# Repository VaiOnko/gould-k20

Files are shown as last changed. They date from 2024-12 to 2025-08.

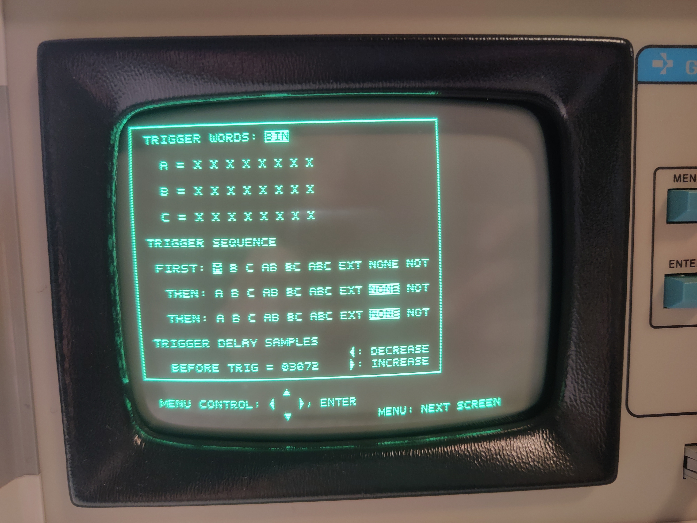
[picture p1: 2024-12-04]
pictures/menus/menu8.jpg

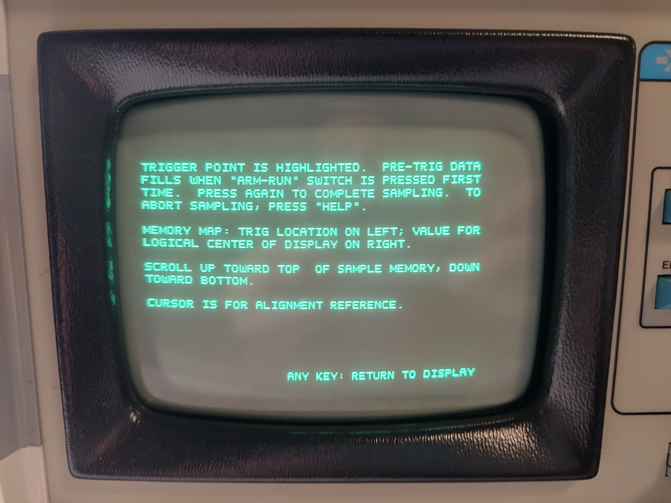
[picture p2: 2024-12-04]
pictures/menus/menu1.jpg

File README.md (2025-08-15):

# gould-k20

This probe is tested and works well according to my test without knowing how the proper thing operates,

This is my project to create a reproduction state mode probe for the Gould K20 logic analyzer and document the unit.

I did not get any probes with the unit, so I had to create my own one from scratch. 
The probe contains logic to route the three clock inputs to any combination of the three clocks on the analyzer. They can also be inverted and ORred together. All this is configured from the unit itself in the menu pictured in menu4.jpg, and sent to a pair of shift registers in the probe. 

The probe connects to the main unit with a 34-pin ribbon cable. I use a PC floppy cable from which I removed the twist. 

The probe should work just like the original state mode probe, but I cannot be sure as I don't know anything about the original one.
The machine also came with an 8-channel timing mode probe. From what I understand, it had a configurable clock generator inside and thus would be quite difficult to recreate. 

The directory "logicanalyzer" contains the KiCad project for the probe. 
The directory "pictures" contains detailed pictures of the unit.
The directory "ROMs" contains dumps from all the ROMs in the system.

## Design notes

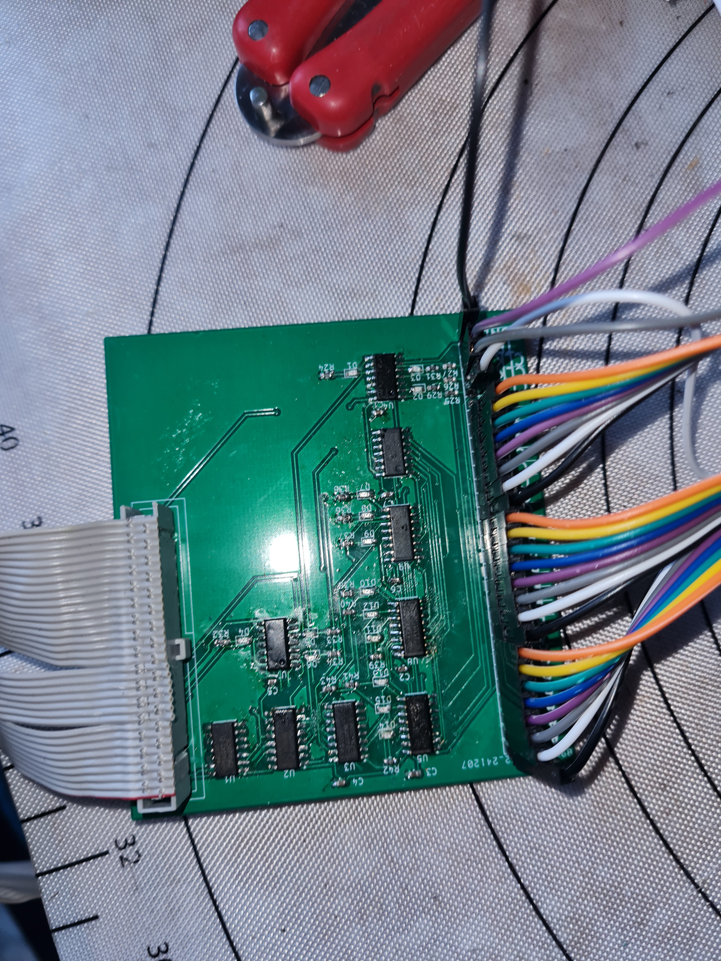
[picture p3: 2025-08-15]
pictures/the-probe.jpg

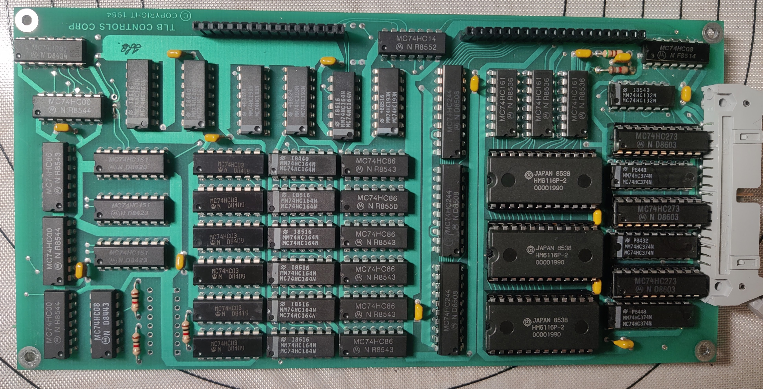
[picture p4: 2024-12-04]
pictures/interior/acquisition-board-1.jpg

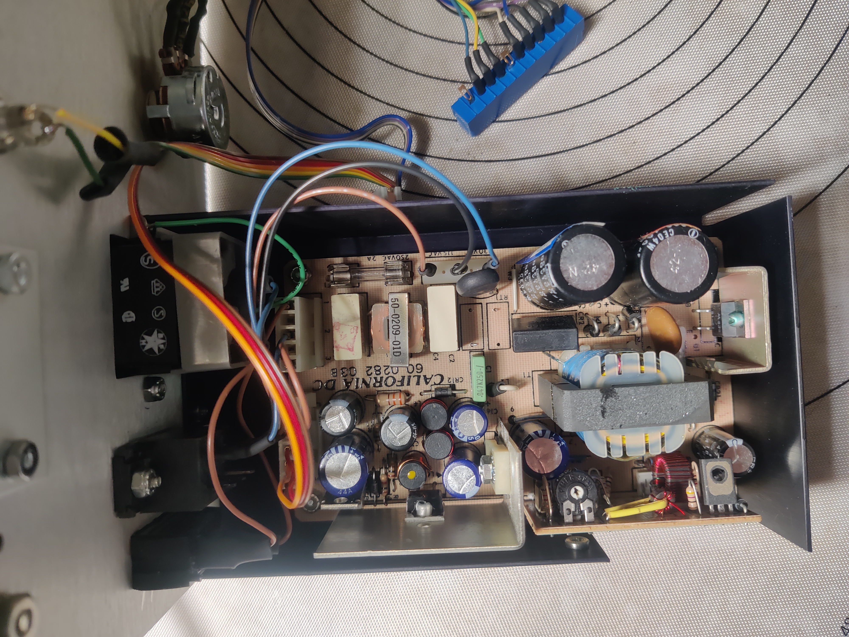
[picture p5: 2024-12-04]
pictures/interior/power-supply.jpg

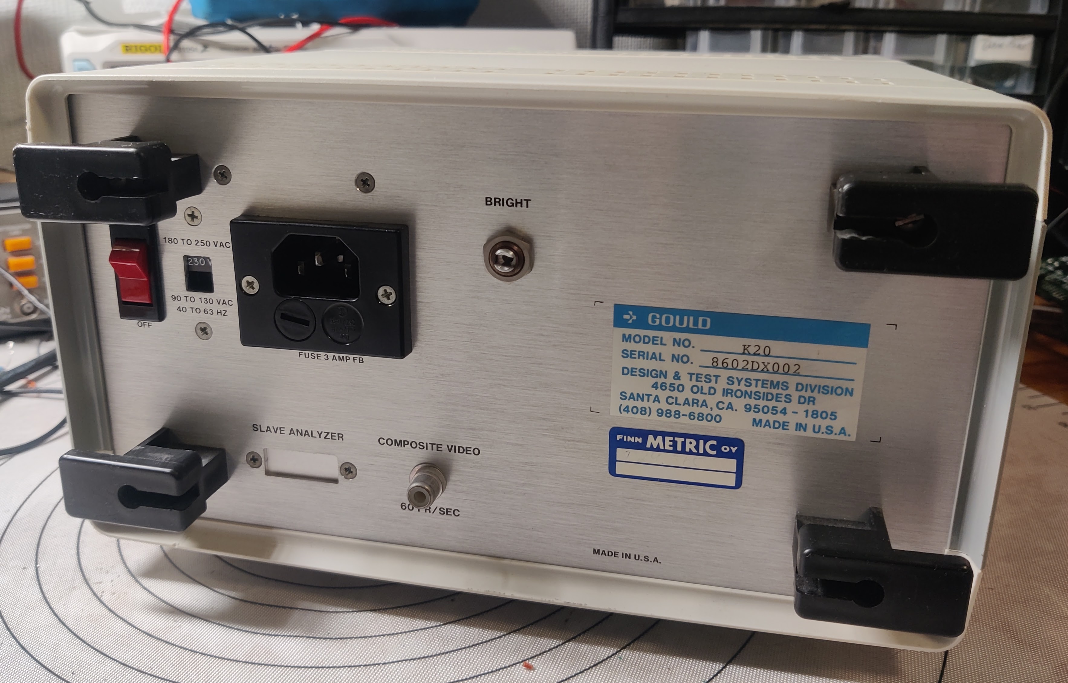
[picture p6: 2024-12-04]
pictures/exterior/rear.jpg

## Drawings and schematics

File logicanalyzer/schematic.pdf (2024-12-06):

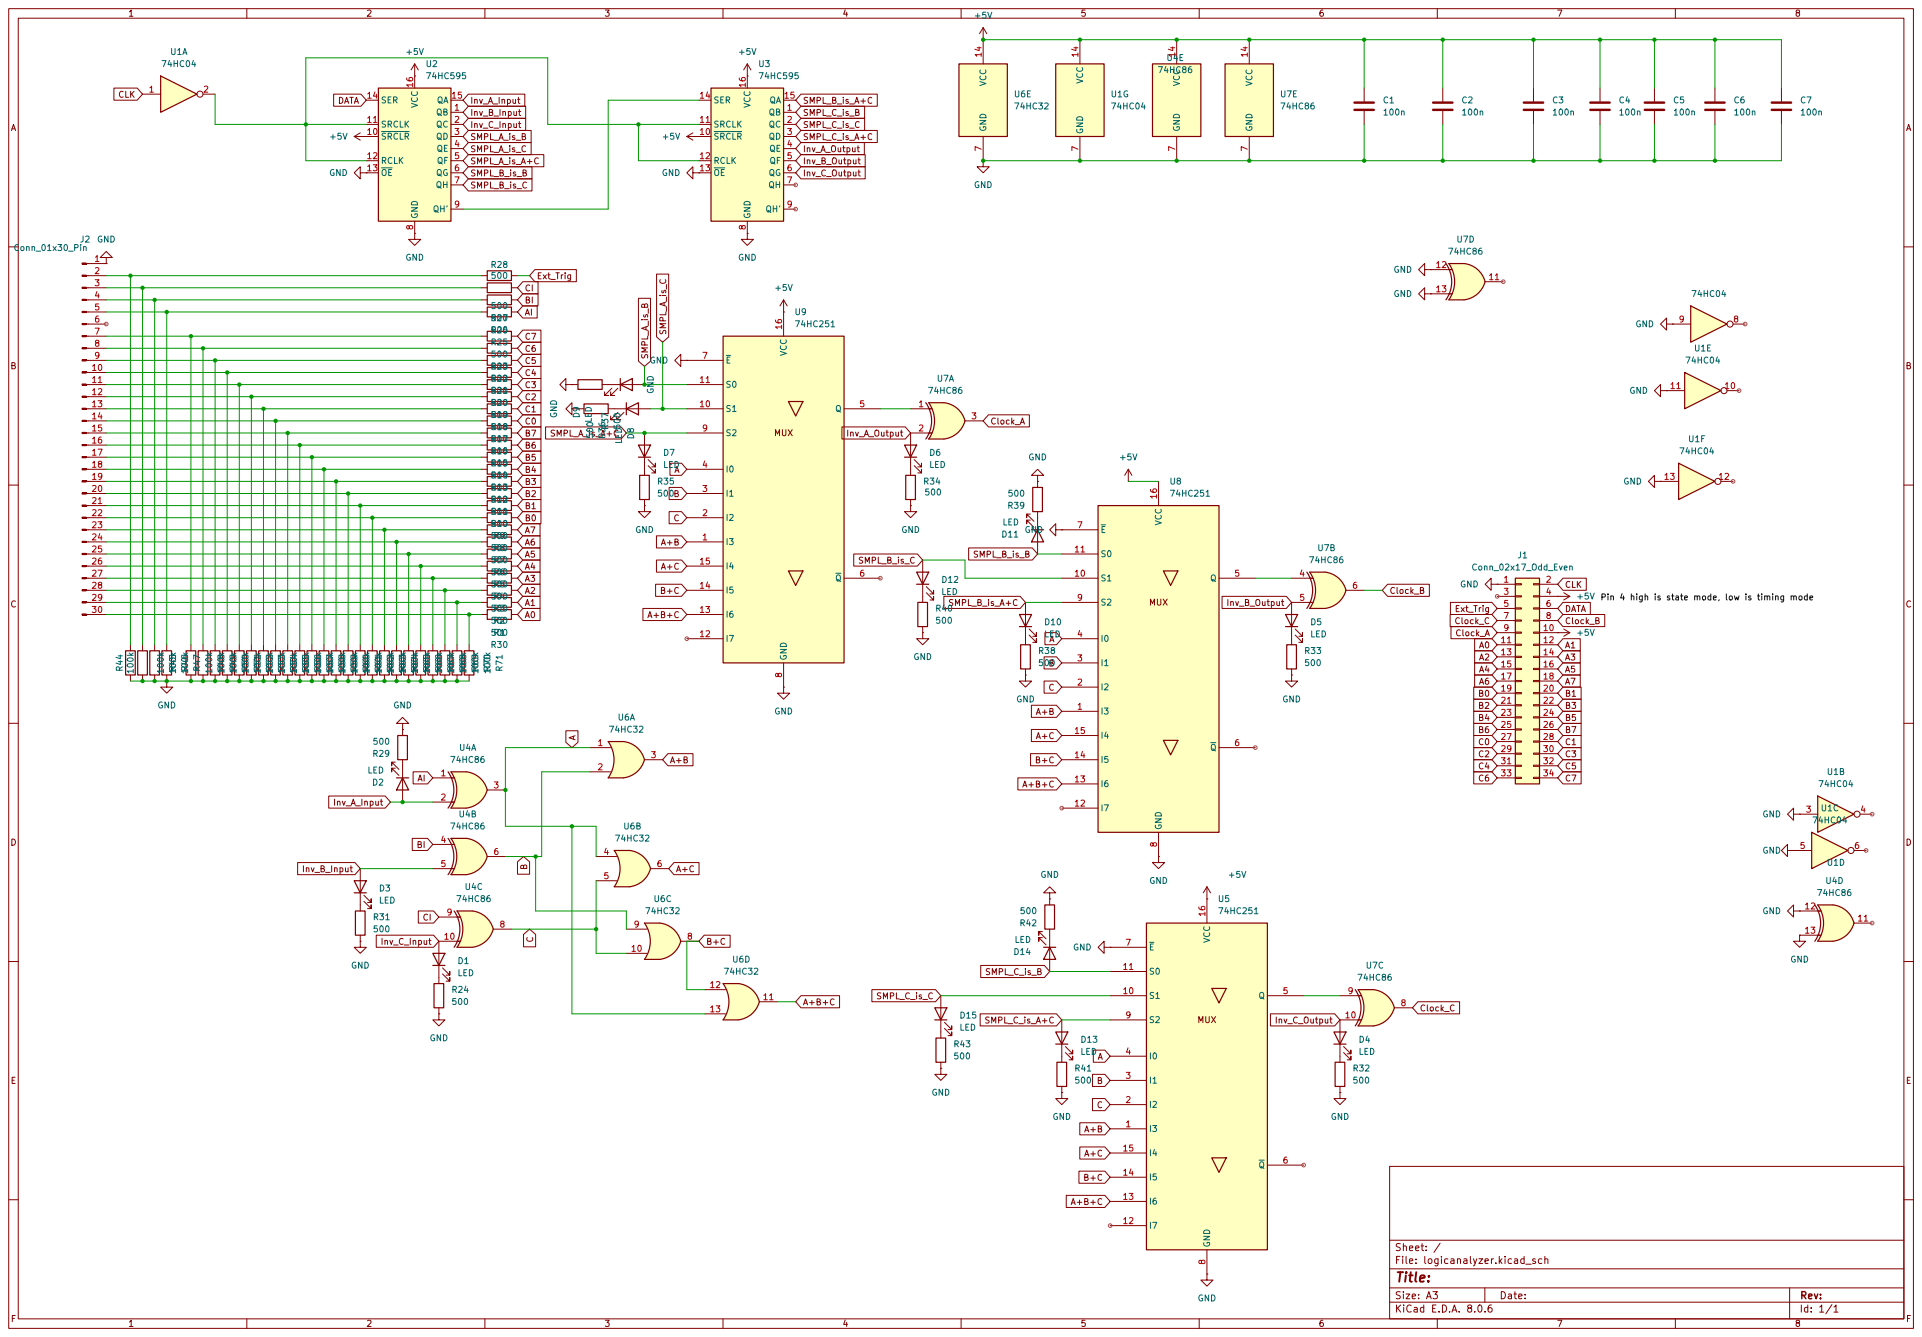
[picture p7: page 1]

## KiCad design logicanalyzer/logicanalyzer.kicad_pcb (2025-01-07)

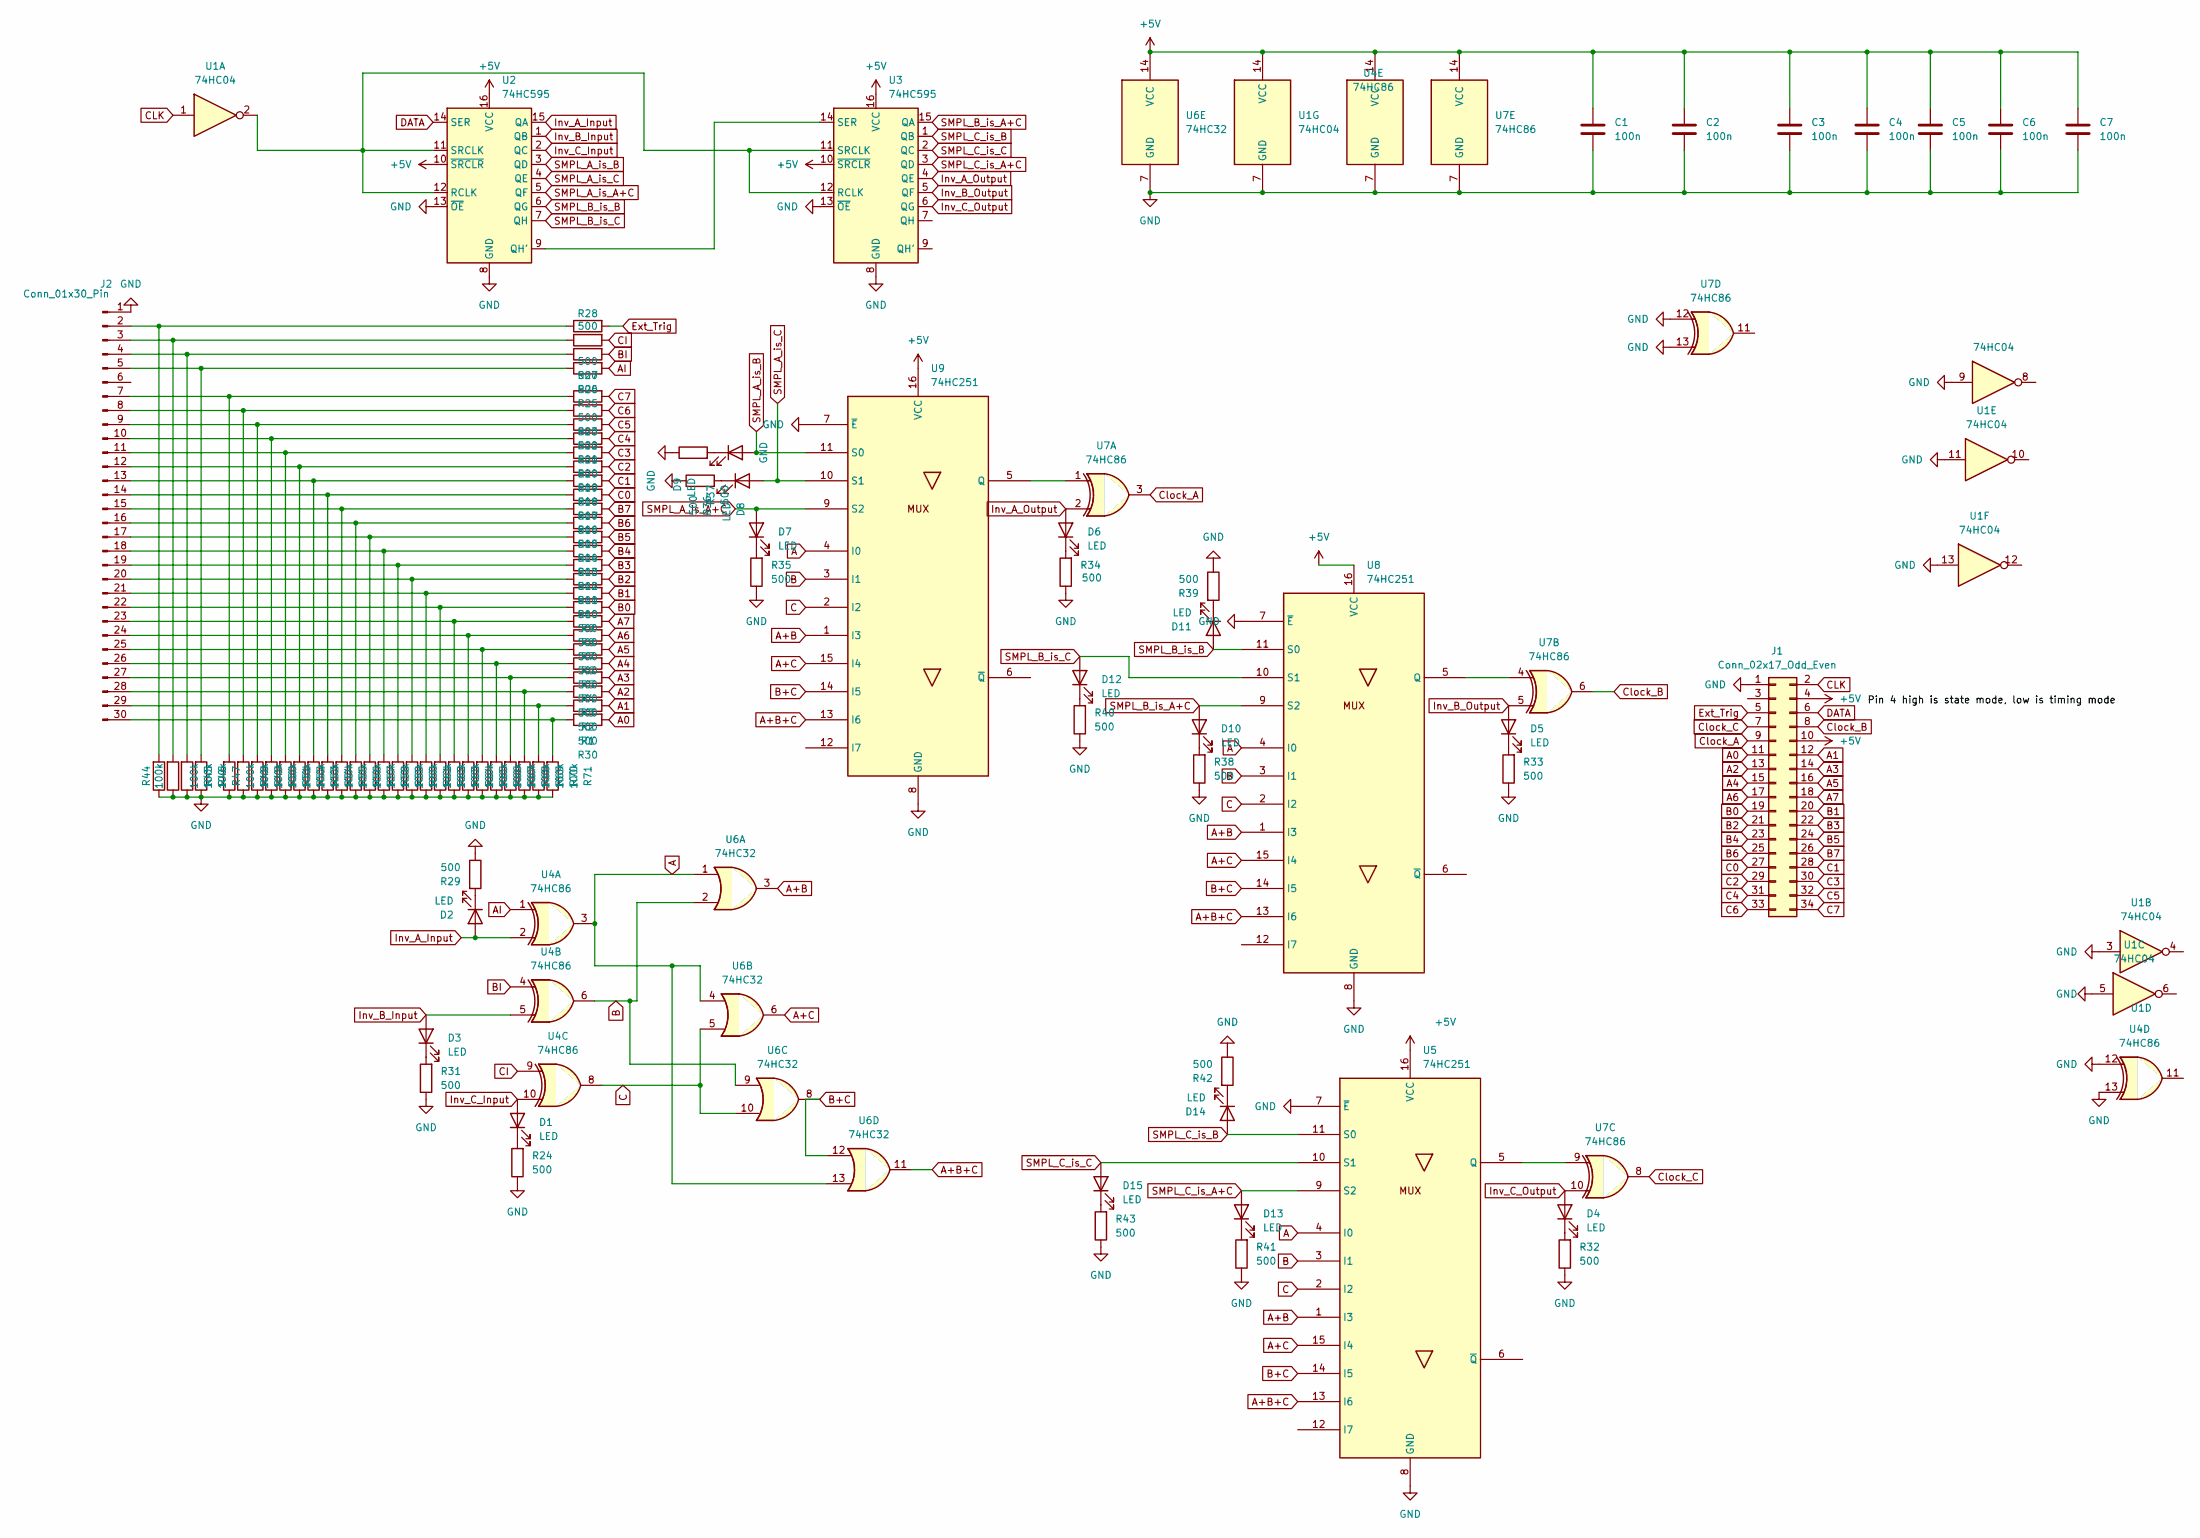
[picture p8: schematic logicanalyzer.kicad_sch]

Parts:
C1, C2, C3, C4, C5, C6, C7: 100n; C_0603_1608Metric
D1, D2, D3, D4, D5, D6, D7, D8, D9, D10, D11, D12, D13, D14, D15: LED; LED_0603_1608Metric
J1: Conn_02x17_Odd_Even; IDC-Header_2x17_P2.54mm_Vertical
J2: Conn_01x30_Pin; PinHeader_1x30_P2.54mm_Vertical
R1, R2, R3, R4, R5, R6, R7, R8, R9, R10, R11, R12, R13, R14, R15, R16, R17, R18, R19, R20, R21, R22, R23, R24, R25, R26, R27, R28, R29, R30, R31, R32, R33, R34, R35, R36, R37, R38, R39, R40, R41, R42, R43: 500; R_0603_1608Metric
R44, R45, R46, R47, R48, R49, R50, R51, R52, R53, R54, R55, R56, R57, R58, R59, R60, R61, R62, R63, R64, R65, R66, R67, R68, R69, R70, R71: 100k; R_0603_1608Metric
U1: 74HC04; SOIC-14_3.9x8.7mm_P1.27mm
U2, U3: 74HC595; SOIC-16_3.9x9.9mm_P1.27mm
U4, U7: 74HC86; SOIC-14_3.9x8.7mm_P1.27mm
U5, U8, U9: 74HC251; SOIC-16_3.9x9.9mm_P1.27mm
U6: 74HC32; SOIC-14_3.9x8.7mm_P1.27mm

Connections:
+5V: C1.1, C2.1, C3.1, C4.1, C5.1, C6.1, C7.1, J1.4, J1.10, U1.14 (VCC), U2.10 (~SRCLR), U2.16 (VCC), U3.10 (~SRCLR), U3.16 (VCC), U4.14 (VCC), U5.16 (VCC), U6.14 (VCC), U7.14 (VCC), U8.16 (VCC), U9.16 (VCC)
A: U4.3, U5.4 (I0), U6.1, U6.4, U6.13, U8.4 (I0), U9.4 (I0)
A0: J1.11, R30.2
A1: J1.12, R1.2
A2: J1.13, R2.2
A3: J1.14, R3.2
A4: J1.15, R4.2
A5: J1.16, R5.2
A6: J1.17, R6.2
A7: J1.18, R7.2
A+B: U5.1 (I3), U6.3, U8.1 (I3), U9.1 (I3)
A+B+C: U5.13 (I6), U6.11, U8.13 (I6), U9.13 (I6)
A+C: U5.15 (I4), U6.6, U8.15 (I4), U9.15 (I4)
AI: R25.2, U4.1
B: U4.6, U5.3 (I1), U6.2, U6.9, U8.3 (I1), U9.3 (I1)
B0: J1.19, R8.2
B1: J1.20, R9.2
B2: J1.21, R10.2
B3: J1.22, R11.2
B4: J1.23, R12.2
B5: J1.24, R13.2
B6: J1.25, R14.2
B7: J1.26, R15.2
B+C: U5.14 (I5), U6.8, U6.12, U8.14 (I5), U9.14 (I5)
BI: R26.2, U4.4
C: U4.8, U5.2 (I2), U6.5, U6.10, U8.2 (I2), U9.2 (I2)
C0: J1.27, R16.2
C1: J1.28, R17.2
C2: J1.29, R18.2
C3: J1.30, R19.2
C4: J1.31, R20.2
C5: J1.32, R21.2
C6: J1.33, R22.2
C7: J1.34, R23.2
CI: R27.2, U4.9
CLK: J1.2, U1.1
Clock_A: J1.9, U7.3
Clock_B: J1.8, U7.6
Clock_C: J1.7, U7.8
DATA: J1.6, U2.14 (SER)
Ext_Trig: J1.5, R28.2
GND: C1.2, C2.2, C3.2, C4.2, C5.2, C6.2, C7.2, J1.1, J2.1, R24.1, R29.1, R31.1, R32.1, R33.1, R34.1, R35.1, R36.1, R37.1, R38.1, R39.1, R40.1, R41.1, R42.1, R43.1, R44.1, R45.1, R46.1, R47.1, R48.1, R49.1, R50.1, R51.1, R52.1, R53.1, R54.1, R55.1, R56.1, R57.1, R58.1, R59.1, R60.1, R61.1, R62.1, R63.1, R64.1, R65.1, R66.1, R67.1, R68.1, R69.1, R70.1, R71.1, U1.3, U1.5, U1.7 (GND), U1.9, U1.11, U1.13, U2.8 (GND), U2.13 (~OE), U3.8 (GND), U3.13 (~OE), U4.7 (GND), U4.12, U4.13, U5.7 (~E), U5.8 (GND), U6.7 (GND), U7.7 (GND), U7.12, U7.13, U8.7 (~E), U8.8 (GND), U9.7 (~E), U9.8 (GND)
Inv_A_Input: D2.2 (A), U2.15 (QA), U4.2
Inv_A_Output: D6.2 (A), U3.4 (QE), U7.2
Inv_B_Input: D3.2 (A), U2.1 (QB), U4.5
Inv_B_Output: D5.2 (A), U3.5 (QF), U7.5
Inv_C_Input: D1.2 (A), U2.2 (QC), U4.10
Inv_C_Output: D4.2 (A), U3.6 (QG), U7.10
unnamed: D1.1 (K), R24.2
unnamed: D2.1 (K), R29.2
unnamed: D3.1 (K), R31.2
unnamed: D4.1 (K), R32.2
unnamed: D5.1 (K), R33.2
unnamed: D6.1 (K), R34.2
unnamed: D7.1 (K), R35.2
unnamed: D8.1 (K), R36.2
unnamed: D9.1 (K), R37.2
unnamed: D10.1 (K), R38.2
unnamed: D11.1 (K), R39.2
unnamed: D12.1 (K), R40.2
unnamed: D13.1 (K), R41.2
unnamed: D14.1 (K), R42.2
unnamed: D15.1 (K), R43.2
unnamed: J2.2, R28.1, R44.2
unnamed: J2.3, R27.1, R45.2
unnamed: J2.4, R26.1, R46.2
unnamed: J2.5, R25.1, R47.2
unnamed: J2.7, R23.1, R48.2
unnamed: J2.8, R22.1, R49.2
unnamed: J2.9, R21.1, R50.2
unnamed: J2.10, R20.1, R51.2
unnamed: J2.11, R19.1, R52.2
unnamed: J2.12, R18.1, R53.2
unnamed: J2.13, R17.1, R54.2
unnamed: J2.14, R16.1, R55.2
unnamed: J2.15, R15.1, R56.2
unnamed: J2.16, R14.1, R57.2
unnamed: J2.17, R13.1, R58.2
unnamed: J2.18, R12.1, R59.2
unnamed: J2.19, R11.1, R60.2
unnamed: J2.20, R10.1, R61.2
unnamed: J2.21, R9.1, R62.2
unnamed: J2.22, R8.1, R63.2
unnamed: J2.23, R7.1, R64.2
unnamed: J2.24, R6.1, R65.2
unnamed: J2.25, R5.1, R66.2
unnamed: J2.26, R4.1, R67.2
unnamed: J2.27, R3.1, R68.2
unnamed: J2.28, R2.1, R69.2
unnamed: J2.29, R1.1, R70.2
unnamed: J2.30, R30.1, R71.2
unnamed: U2.9 (QH'), U3.14 (SER)
unnamed: U1.2, U2.11 (SRCLK), U2.12 (RCLK), U3.11 (SRCLK), U3.12 (RCLK)
unnamed: U5.5 (Q), U7.9
unnamed: U7.4, U8.5 (Q)
unnamed: U7.1, U9.5 (Q)
SMPL_A_is_A+C: D7.2 (A), U2.5 (QF), U9.9 (S2)
SMPL_A_is_B: D9.2 (A), U2.3 (QD), U9.11 (S0)
SMPL_A_is_C: D8.2 (A), U2.4 (QE), U9.10 (S1)
SMPL_B_is_A+C: D10.2 (A), U3.15 (QA), U8.9 (S2)
SMPL_B_is_B: D11.2 (A), U2.6 (QG), U8.11 (S0)
SMPL_B_is_C: D12.2 (A), U2.7 (QH), U8.10 (S1)
SMPL_C_is_A+C: D13.2 (A), U3.3 (QD), U5.9 (S2)
SMPL_C_is_B: D14.2 (A), U3.1 (QB), U5.11 (S0)
SMPL_C_is_C: D15.2 (A), U3.2 (QC), U5.10 (S1)

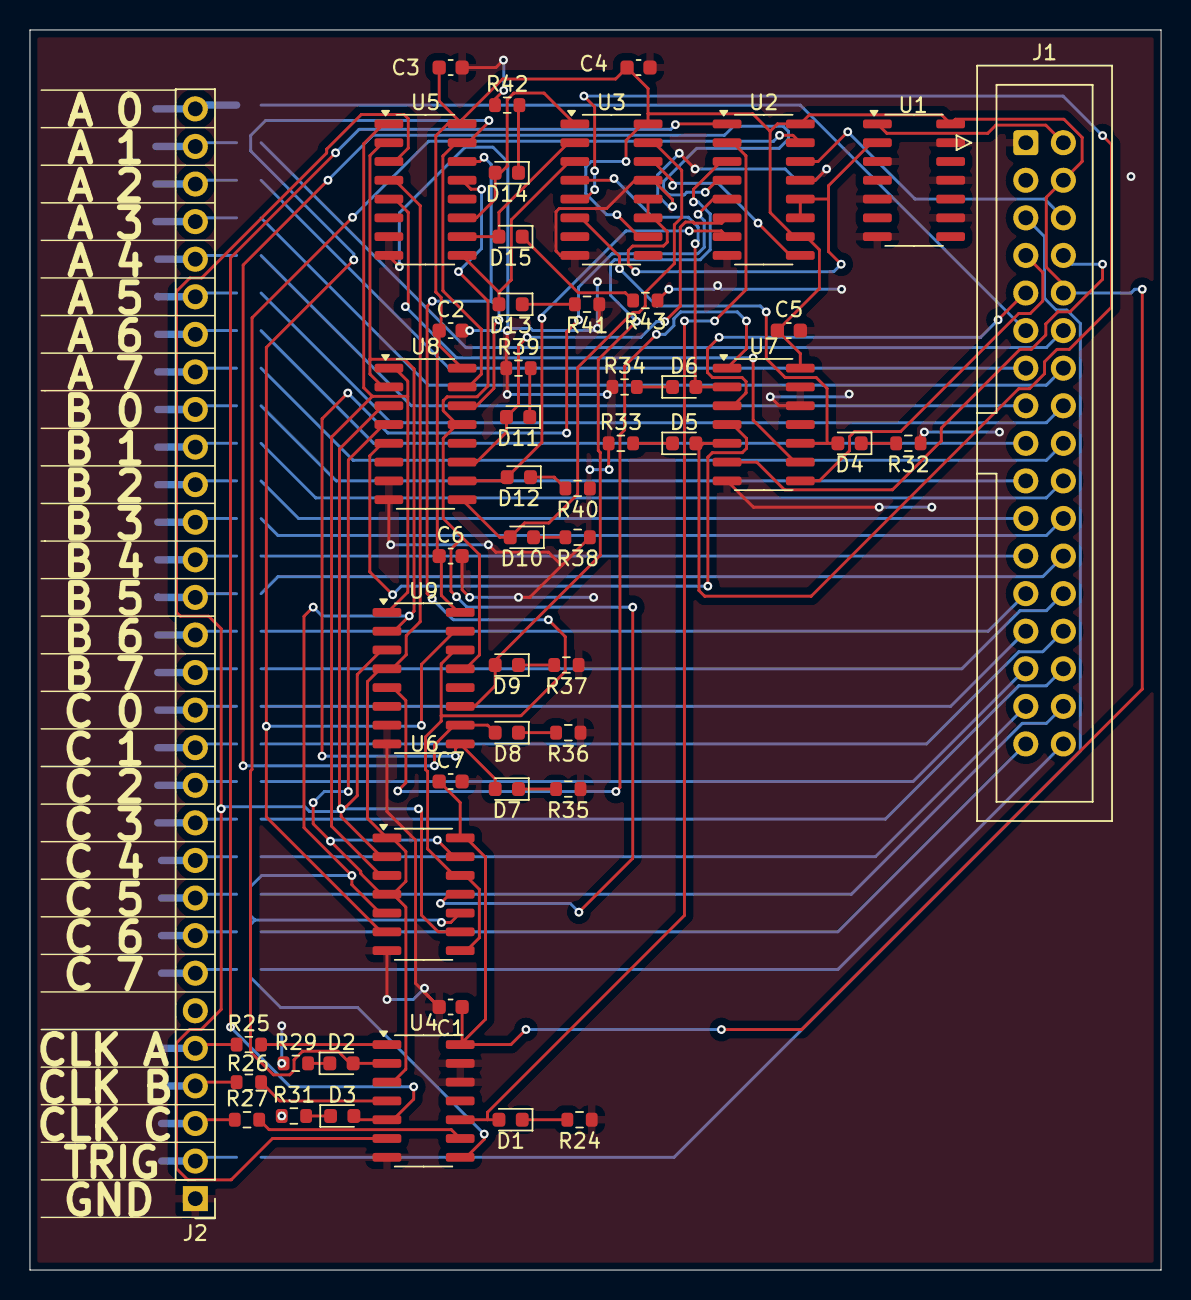
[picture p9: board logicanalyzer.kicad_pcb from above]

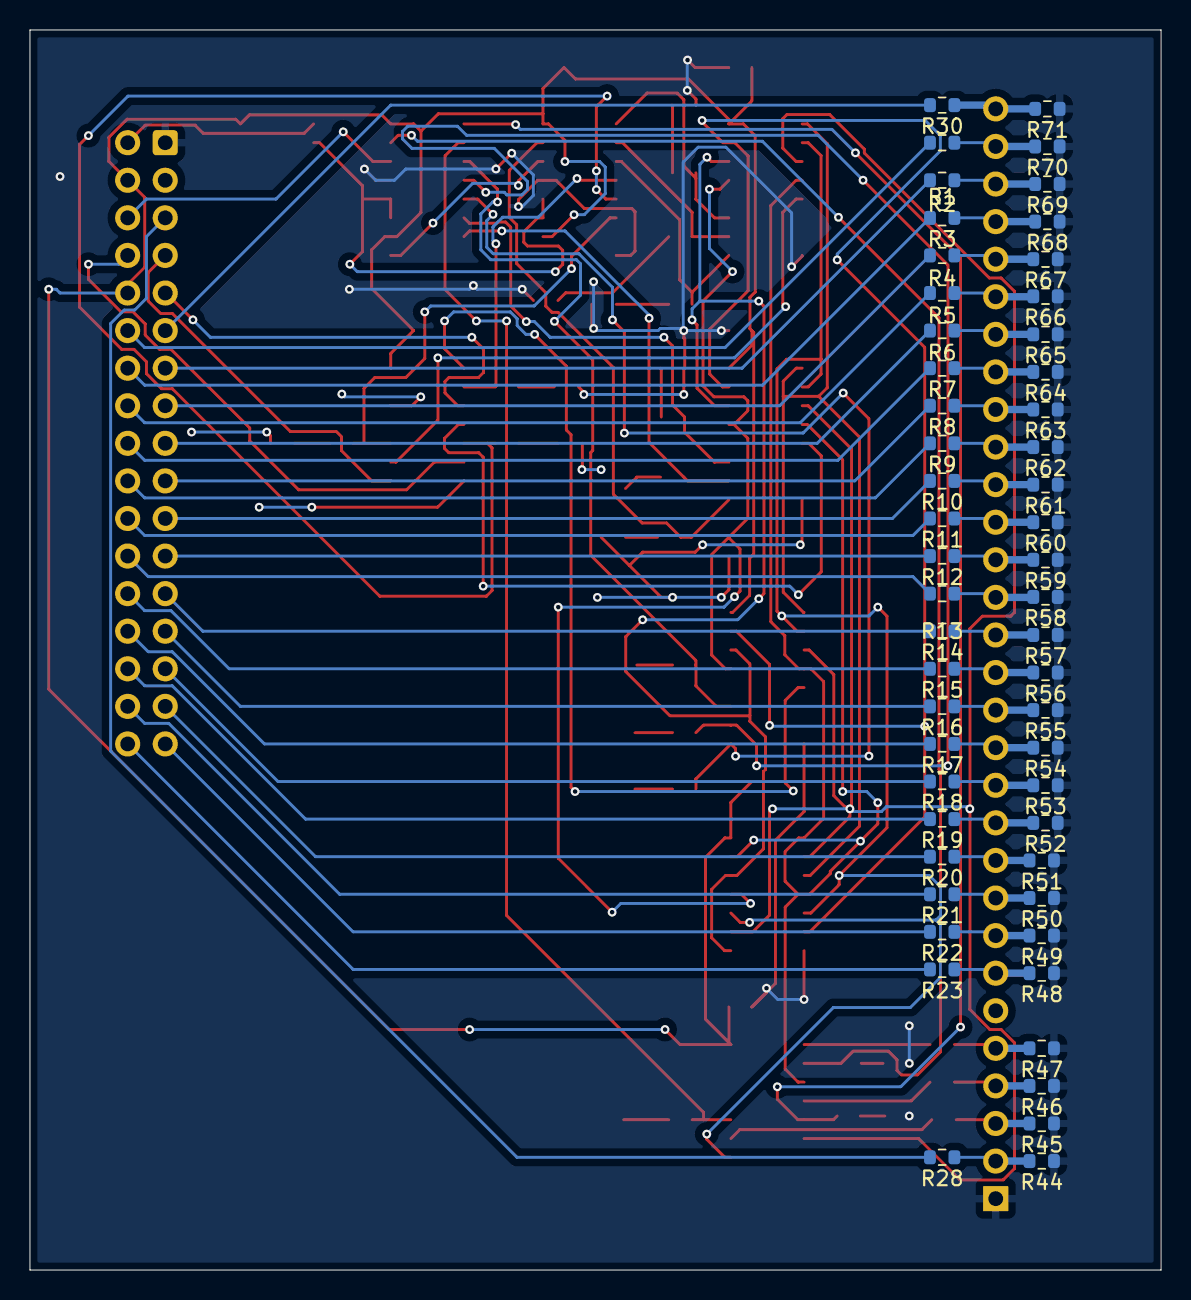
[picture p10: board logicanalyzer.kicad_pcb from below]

Board: 2 copper layers, 76.5 x 83.8 mm, 104 parts (53 on the bottom side), 105 nets.

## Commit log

2024-12-04 Add KiCad project
    [logicanalyzer.kicad_pcb, logicanalyzer.kicad_sch]
2024-12-04 Schematic changes
    [logicanalyzer.kicad_sch]
2024-12-04 Schematic change + typo in README
    [logicanalyzer.kicad_sch]
2024-12-06 Finalized PCB, added gerbers and pdf schematic
    [logicanalyzer.kicad_sch]
2025-01-07 Add ROM dumps
    [logicanalyzer-B_Cu.gbr, logicanalyzer-B_Mask.gbr, logicanalyzer-B_Paste.gbr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]
2025-08-15 Added picture and info about probe being tested
